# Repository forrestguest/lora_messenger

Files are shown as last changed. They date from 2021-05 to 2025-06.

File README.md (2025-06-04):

# lora_messenger
LORA Wireless Messenger

Some refinements to the project shown at:
https://msglab.co/room/lo-ra-msg

Notable improvements:
- Messages are encrypted
- Devices have names for better scrollback
- Some small bugs fixed
- Buttons all do something (mostly just change the color of the LED)
- I adjusted the STLs to fit the larger USB plugs I'm using

This project is mostly just a combination of free resources and developer boards.

Shopping list:
- Keyboard featherwing: https://www.tindie.com/products/arturo182/keyboard-featherwing-qwerty-keyboard-26-lcd/
- Feather m4: https://www.adafruit.com/product/3857
- LORA Featherwing: https://www.adafruit.com/product/3231
- A set of featherwing headers: https://www.adafruit.com/product/2940
- A 1200 mAh lipo battery pack: https://www.adafruit.com/product/258
- Antenna to ufl pad: https://www.adafruit.com/product/1661
- A stubby antenna: https://www.amazon.com/gp/product/B086ZG5WBR/
- m3 bolts: https://www.amazon.com/gp/product/B07H17DQDG/
- heat inserts: https://www.amazon.com/gp/product/B07HKW7LKH/
- Wrist Strap: https://www.amazon.com/gp/product/B0832CKB59/
- 3d printed case (see STL files)
- Tools
  - A 3d Printer
  - A soldering iron (with fine tip for soldering and 2mm tip for heat inserts)
  - Solder
  - Hook up wire
  - A computer
  - A USB to mini USB cable
  - A 2.5mm allen wrench
  - Offset tweezers: https://www.amazon.com/dp/B006RBBE3I/

More information:
Stores: Adafruit things are available in a variety of locations, their store charges shipping but is otherwise the cheapest option for the feather and LORA featherwing.  I would also recommend buying the headers from them, as batteries from another source may have reversed polarity.  Check the battery image at Adafruit against the battery you get to make sure you don't break anything.  Tindie, Adafruit, Digikey and of course Amazon are all places to check.

The blackberry q10 keyboard featherwing is from https://www.solder.party/, made by https://twitter.com/arturo182.  
Docs: https://www.solder.party/docs/keyboard-featherwing/
Code: https://github.com/arturo182/keyboard_featherwing_sw

The feather m4 comes in two versions, either is fine.  One has CAN bus support and costs a few dollars more.

The LORA featherwing I use is the 900 MHz (915 MHz) for the US.  Here's a page giving the recommended version by country: https://www.thethingsnetwork.org/docs/lorawan/frequencies-by-country/index.html.  TLDR; Americas 900 MHz, EU 433MHz

I used 1500 mAh lipo battery pack.  Don't be tempted to go with a bigger one, it won't fit in the case.  I haven't managed to run out of battery yet.  As mentioned in the stores section above, make sure the polarity is correct for the Adafruit standard so the feather can charge and use the battery.

For 3d printed case, use three walls in your slicer for the bottom, you'll need the reinforcement for the heat set inserts.

You can use whatever antenna you want, but the case looks nice with the little stubby one.

I like the look of the hex bolts, you will probably have to clean up your print a little around all of the holes.  I also bought a little m3 tap, which I used before I put in the heat inserts.  The heat inserts go in very quickly, don't waste time when you're putting them in or you could melt it through the side of the hole.

Instructions:
1. Download everything you'll need
    - The code.py and msg_config.json from this repository
    - The encryption libraries from this repository (source: https://www.nayuki.io/page/cryptographic-primitives-in-plain-python)
    - The Mu code editor (https://codewith.mu/)
    - The circuitpython installer (https://circuitpython.org/board/feather_m4_express/)
    - The circuitpython libraries (https://circuitpython.org/libraries)
 2. Install Mu on your computer
 3. Assemble the LORA featherwing by soldering on the uFL connector and the two fly wires - CS to A3 and RST to A4, if you want to use the code without changes
 4. Solder on all of the headers.  I put some of the headers on upside down in order to keep the boards as close to the screen as possible.  Don't put the case on yet.
 5. Open Mu and plug in the USB cable
 6. Double click the reset button to put the feather into flashing mode.  The USB drive should disappear and you should get a drive named *SOMETHING*BOOT
 7. Copy and paste the circuitpython UF2 onto the drive.  It should reboot, and the drive name should switch back to CIRCUITPY.
 8. Open the boot.txt and make sure the version has been updated.
 9. Unplug everything and assemble the case, plug in the battery and antenna. I needed a pair of offset tweezers in order to seat the antenna correctly.
 10. Generate a key.  Open IDLE or another python editor (Mu doesn't seem to have an interactive console), and enter the following commands:
     - import random
     - '%030x' % random.randrange(16**32)
 11. Edit the msg_config.json file and update the key with the result of the above, and set the device name to something useful.  Only 10 characters will be used.
 12. Plug the usb back in and copy the following files into the main drive from this repository:
     - code.py
     - msg_config.json
 13. Edit the 
 14. Copy the following files into the lib directory from the encryption folder of this repository:
     - aescipher.py
     - cryptocommon.py
 15. Copy the following files into the lib directory from the circuitpython library zip file:
     - the entire adafruit_bus_device folder
     - the entire adafruit_display_shapes folder
     - the entire adafruit_display_text folder
     - the entire adafruit_hashlib folder
     - the entire adafruit_register folder
     - adafruit_binascii.mpy
     - adafruit_ili93451.mpy
     - adafruit_logging.mpy
     - adafruit_pct2075.mpy
     - adafruit_rfm9x.mpy
     - adafruit_sdcard.mpy
     - adafruit_stmpe610.mpy
     - bbq10keyboard.py
     - neopixel.mpy
 16. Saving the last file should have restarted the device, and the screen should load up and drop you into a black window 
 17. Realize you need to make at least two devices in order to chat, and repeat all of the above steps for any other devices.

TODO:
- find something for the other buttons to do
- find something for the pointer stick to do
- find out if the touchscreen is useful

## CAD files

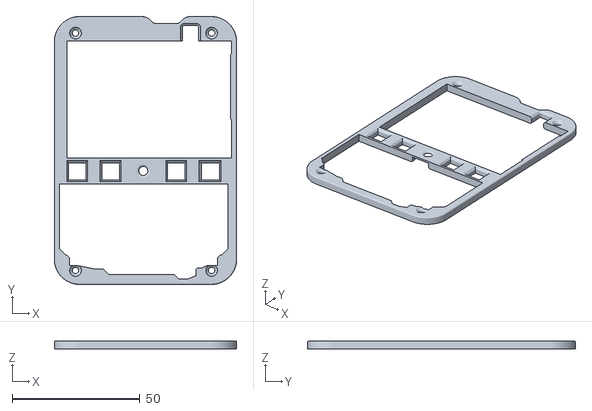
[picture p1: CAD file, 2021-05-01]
lora_msg_front.stl
71.5 x 105.0 x 3.30

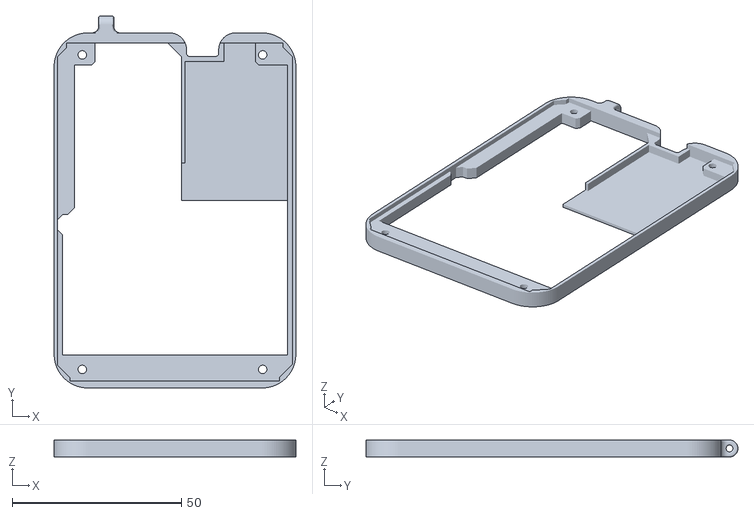
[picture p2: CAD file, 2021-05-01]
lora_msg_mid.stl
71.5 x 110.0 x 5.00

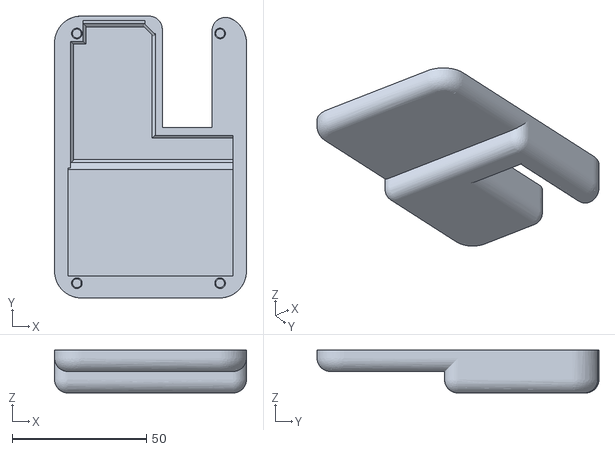
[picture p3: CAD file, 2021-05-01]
lora_msg_back.stl
71.5 x 105.0 x 16.0

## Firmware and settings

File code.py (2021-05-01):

# keyboard featherwing
from bbq10keyboard import BBQ10Keyboard, STATE_PRESS, STATE_RELEASE, STATE_LONG_PRESS
from adafruit_stmpe610 import Adafruit_STMPE610_SPI
import adafruit_ili9341
import adafruit_sdcard
import digitalio
import displayio
import neopixel
import storage
import board
import time
import os
import busio

# config file
import json

# encryption
import aescipher
import cryptocommon

#LORA featherwing
import adafruit_rfm9x

# battery voltage meter
from analogio import AnalogIn

# shapes
from adafruit_display_text.label import Label
from adafruit_display_shapes.rect import Rect

# text to screen
import terminalio
import gc

# Optional Qwiic test
try:
    import adafruit_pct2075
except Exception as e:
    print('Skipping Qwiic test,', e)

all_passed = True

#device name, must be 10 char long

#default name
device_name = "code name "

#read name from file
with open("/msg_config.json", "r") as cfg_fp:
    config_string = cfg_fp.read()
    config = json.loads(config_string)
    device_name = config["device_name"]

# build key from config
key = config["msg_key"]
keybytelist = cryptocommon.hexstr_to_bytelist(key)

#truncate to 10 characters
device_name = device_name[0:10]

#pad with spaces to 10 characters
dev_size = len(device_name)
dev_space = 10 - dev_size
device_name += " " * dev_space

# ui dimensions
header = 16
margin = 0
border = 0

# Release any resources currently in use for the displays
displayio.release_displays()

# board pins
spi = board.SPI()
tft_cs = board.D9
tft_dc = board.D10
touch_cs = board.D6
sd_cs = board.D5
neopix_pin = board.D11

# initialize display module
display_bus = displayio.FourWire(spi, command=tft_dc, chip_select=tft_cs)
display = adafruit_ili9341.ILI9341(display_bus, width=320, height=240)

# battery voltage reader
vbat_voltage = AnalogIn(board.VOLTAGE_MONITOR)

# Define radio parameters.
# Frequency of the radio in Mhz. Must match your
# module! Can be a value like 915.0, 433.0, etc.
RADIO_FREQ_MHZ = 915.0

# Define pins connected to the chip - you must solder fly wires
#  they are not connected from the factory
CS = digitalio.DigitalInOut(board.A3)
RESET = digitalio.DigitalInOut(board.A4)

# Initialize RFM radio
rfm9x = adafruit_rfm9x.RFM9x(spi, CS, RESET, RADIO_FREQ_MHZ)

# Note that the radio is configured in LoRa mode so you can't control sync
# word, encryption, frequency deviation, or other settings!

# You can however adjust the transmit power (in dB).  The default is 13 dB but
# high power radios like the RFM95 can go up to 23 dB:
rfm9x.tx_power = 23

#initialize keyboard featherwing
i2c = board.I2C()
kbd = BBQ10Keyboard(i2c)

splash = displayio.Group(max_size=25)
display.show(splash)

# background
def bg_stripe(x, color):
    width = display.width
    color_bitmap = displayio.Bitmap(width, 240, 1)
    color_palette = displayio.Palette(1)
    color_palette[0] = color
    bg_sprite = displayio.TileGrid(
        color_bitmap, x=x*width, y=0, pixel_shader=color_palette)
    splash.append(bg_sprite)


bg_stripe(0, 0x000000)

# output rect
output_rect = Rect(margin, margin, display.width-margin*2, display.height -
                   margin*2-header-margin, fill=0x000000, outline=0x000000)
splash.append(output_rect)

# output header
header_rect = Rect(margin + border, margin+border,
                   display.width-(margin+border)*2+10, header, fill=0x03447c)
splash.append(header_rect)

#read the battery voltage
def get_voltage(pin):
    return (pin.value * 3.3) / 65536 * 2

# send a message, prepend sender, append eol characters
# and make sure not to send more than 252 bytes at once
# Send a packet.  Note you can only send a packet up to 252 bytes in length.
# This is a limitation of the radio packet size, so if you need to send larger
# amounts of data you will need to break it into smaller send calls.  Each send
# call will wait for the previous one to finish before continuing.
def send_message(msg_to_send):
    # prepare message
    send_string = device_name + ": " + msg_to_send + "\r\n"
    # initialize encrypted byte list
    send_bytes = []

    # convert message to byte list
    plaintextbytelist = cryptocommon.asciistr_to_bytelist(send_string)
    # split message into 16 byte block
    blocks = [plaintextbytelist[i:i+16] for i in range(0, len(plaintextbytelist), 16)]
    for block in blocks:
        # pad block
        block += [0] * (16 - len(block))
        # encrypt
        ciphertextbytelist = aescipher.encrypt(block, keybytelist)
        # add block to full message
        send_bytes.extend(ciphertextbytelist)

    # convert list to byte array
    send_buff = bytearray(send_bytes)
    # split bytes to 252 byte chunks
    chunks = [send_buff[i:i+252] for i in range(0, len(send_buff), 252)]
    for chunk in chunks:
        # pass to LORA module
        rfm9x.send_with_ack(chunk)

    # echo to local device
    term.write(send_string.encode('utf-8'))

# battery info
battery_voltage = get_voltage(vbat_voltage)
battery_level = "{:.2f}".format(battery_voltage)

# signal statistics
rssi = "{0}".format(rfm9x.last_rssi)
snr = "{:.2f}".format(rfm9x.last_snr)

# format header
msg_size = len(" lora " + device_name + " rssi:" + rssi + "  snr:" + snr + "  Bat:" + battery_level)
need_spc = 50 - msg_size
message = " lora " + device_name + (" " * need_spc) + " rssi:" + rssi + "  snr:" + snr + "  Bat:" + battery_level

header_text = Label(terminalio.FONT, text=str(message[0:50]),
                    x=margin * 2+border, y=int(margin+border+header/2), color=0xFFFFFF)
splash.append(header_text)

# output text
p = displayio.Palette(2)
p.make_transparent(0)
p[1] = 0xFFFFFF

w, h = terminalio.FONT.get_bounding_box()
tilegrid = displayio.TileGrid(terminalio.FONT.bitmap, pixel_shader=p, x=margin*2+border, y=int(
    margin+border+header+margin/2), width=48, height=15, tile_width=w, tile_height=h)
term = terminalio.Terminal(tilegrid, terminalio.FONT)
splash.append(tilegrid)

# input textarea
input_rect = Rect(margin, display.height-header-3,
                  display.width, header, fill=0x000000, outline=0x000000)
splash.append(input_rect)

# input text
max_input_char = 50
input_text = Label(terminalio.FONT, text='', x=margin*2+border,
                   y=int(display.height-margin-border-header*0.7), color=0xFFFFFF, max_glyphs=max_input_char)
splash.append(input_text)

# carret
carret = Rect(input_text.x + input_text.bounding_box[2] + 1, int(
    display.height-margin-header/2-header/4), 1, header//2, fill=0xFFFFFF)
splash.append(carret)

send_message("online - commlink open")

carret_blink_time = time.monotonic()
carret_blink_state = True

bat_refresh_time = time.monotonic()
bat_refresh_state = True

pixels = neopixel.NeoPixel(neopix_pin, 1)

run = 1

while True:
    packet = None
    packet = rfm9x.receive(with_ack=True)
    pixels[0] = [0, 0, 0]

    if packet is None:
        pixels[0] = [0, 0, 0]
        kbd.backlight = 0.5
    else:
        # Received a packet!
        # flash the LED
        pixels[0] = 0x03447c
        pixels.brightness = 0.05

        # And decode to ASCII text and print it too.  Note that you always
        # receive raw bytes and need to convert to a text format like ASCII
        # if you intend to do string processing on your data.  Make sure the
        # sending side is sending ASCII data before you try to decode!
        try:
            packet_text = ""
            packetbytelist = list(packet)
            blocks = [packetbytelist[i:i+16] for i in range(0, len(packetbytelist), 16)]
            for block in blocks:
                ascii_bytes = aescipher.decrypt(block, keybytelist)
                ascii_list = bytearray(ascii_bytes)
                packet_text += str(ascii_list, "ascii")
        except Exception as e:
            packet_text = "problem receiving message:\r\n" + str(e) + "\r\n"

        term.write("{0}".format(packet_text))

    # Carret blink animation
    if time.monotonic() - carret_blink_time >= 0.01:
        if carret_blink_state:
            splash.remove(carret)
        else:
            splash.append(carret)

        carret_blink_state = not carret_blink_state
        carret_blink_time = time.monotonic()

    # Process keyboard
    while kbd.key_count > 0:
        k = kbd.key
        if k[0] == STATE_PRESS:
            if k[1] == '\x06':  # L1
                pixels[0] = 0xdaf7a6
                pixels.brightness = 0.05
            if k[1] == '\x11':  # L2
                pixels[0] = 0xc70039
                pixels.brightness = 0.05
            if k[1] == '\x07':  # R1
                pixels[0] = 0x33ff3f
                pixels.brightness = 0.05
            if k[1] == '\x12':  # R2
                pixels[0] = 0x4233ff
                pixels.brightness = 0.05
            if k[1] == '\x08':  # Backspace
                if len(input_text.text) > 0:
                    input_text.text = input_text.text[:-1]
            elif k[1] == '\n':
                if len(input_text.text) > 0:
                    text = input_text.text
                    send_message(text)
                    input_text.text = ''
            else:  # Anything else, we add to the text field
                if len(input_text.text) < max_input_char:
                    input_text.text += k[1]

            carret.x = input_text.x + input_text.bounding_box[2] + 1

    if time.monotonic() - bat_refresh_time >= 10:
        if bat_refresh_state:
            # battery charge
            battery_voltage = get_voltage(vbat_voltage)
            battery_level = "{:.2f}".format(battery_voltage)

            # signal statistics
            rssi = "{0}".format(rfm9x.last_rssi)
            snr = "{:.2f}".format(rfm9x.last_snr)

            header_text.text = str(" lora " + device_name + "   "
                                + " rssi:" + rssi
                                + "  snr:" + snr
                                + "  Bat:" + battery_level)
        bat_refresh_state = not bat_refresh_state
        bat_refresh_time = time.monotonic()
